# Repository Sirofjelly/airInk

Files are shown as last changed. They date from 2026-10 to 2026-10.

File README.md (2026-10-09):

# airInk

A compact ESPHome air-quality monitor built with a Sensirion SEN66, a Seeed Studio XIAO ESP32-C3, and a 1.54-inch black-and-white e-paper display.

The 200×200 black-on-white screen is made to be read from a desk at 30–40 cm. Chueli the cow shows how the air feels, with a status line in Swiss German, and all measurements are exposed to Home Assistant.

## Features

- Big CO₂, temperature, and humidity readings in Atkinson Hyperlegible Next
- Chueli the cow, with one face per air-quality status
- PM2.5 and VOC in the footer; NOx appears there when it is the reason for the status
- PM1.0, PM4.0, PM10, and NOx sent to Home Assistant
- Offline display operation after boot
- Home Assistant native API
- USB logging and ESPHome OTA updates
- Periodic full refresh to limit e-paper ghosting

## Hardware

- Sensirion SEN66
- Seeed Studio XIAO ESP32-C3
- Waveshare-compatible 1.54-inch, 200×200 black-and-white e-paper module

The display configuration currently targets ESPHome's `1.54inv2` model.

## Wiring

| XIAO pin | GPIO | SEN66 | E-paper |
|---|---:|---|---|
| D4 | 6 | SDA | — |
| D5 | 7 | SCL | — |
| D8 | 8 | — | CLK/SCL |
| D10 | 10 | — | DIN/SDA |
| D2 | 4 | — | RST/RES |
| D1 | 3 | — | DC |
| D0 | 2 | — | CS |
| D7 | 20 | — | BUSY |
| 3V3 | — | VDD | VCC |
| GND | — | GND | GND |

On the display, `SCL` and `SDA` are SPI clock and data labels; they are not an I²C bus.

Use 3.3 V power and logic. Add 4.7–10 kΩ pull-ups from SEN66 SDA and SCL to 3.3 V if they are not already present on your cable or breakout. GPIO2 and GPIO8 are ESP32-C3 strapping pins, so attached hardware must not force them to an invalid level during boot.

## Build and install

Install ESPHome in a Python virtual environment:

```bash
python3 -m venv .venv
source .venv/bin/activate
pip install esphome
```

Create your local secrets file:

```bash
cp secrets.example.yaml secrets.yaml
```

Edit `secrets.yaml`, then validate and install:

```bash
esphome config sen66-air-monitor.yaml
esphome run sen66-air-monitor.yaml
```

For the first USB installation, put the XIAO into its bootloader if necessary by holding **BOOT** while connecting USB.

## Statuses

Only one status is shown at a time; the first matching row wins. The thresholds live at the top of [`airink.h`](airink.h).

| Status | When | Chueli |
|---|---|---|
| Chueli wacht uf… | sensor still warming up | snoozing |
| Brännt's öppe? | PM2.5 above 50 µg/m³ | wide-eyed, smoke clouds |
| Fänschter uf! | CO₂ above 1400 ppm | dizzy, bell ringing |
| Raclette-Ziit? | VOC above 200 and PM2.5 above 15 on a November–March evening | licking her lips |
| Hesch gfurzt? | VOC rises by 100 or more within 5 minutes | squinting, stink lines |
| Zürcherstrass! | NOx index above 20 | coughing |
| Bitzeli stickig. | CO₂ 1000–1400 ppm | yawning |
| Z'heiss. | above 25 °C | sweating |
| Pulli aalegge. | below 19 °C | scarf, shivering |
| Hallebad-Luft. | humidity above 65 % | water drops |
| Wie i de Sahara. | humidity below 35 % | tongue out, sun |
| Alles guet. / Tiptop. / Muuh-tastisch. | everything fine (rotates every ten minutes) | happy |

## Chueli images

The faces in `images/chueli/` are generated as 1-bit PNGs from the drawings in [`tools/make_chueli.py`](tools/make_chueli.py). After changing a drawing, regenerate them with:

```bash
brew install librsvg
python tools/make_chueli.py
```

The script needs Pillow, which is already installed in the ESPHome virtual environment.

## Configuration

- Change `rotation: 90` to `rotation: 270` if the display is upside down in your enclosure.
- Change `timezone: Europe/Zurich` to your local timezone.
- If an older display is used, try `model: 1.54in` instead of `1.54inv2`.
- Tune the comfort zone and the other status thresholds in [`airink.h`](airink.h).

The display refreshes once per minute and performs a full refresh every ten updates.

The e-paper RST line is held high by an internal switch instead of being given to the display as `reset_pin`. With `reset_pin`, ESPHome resets the panel before every update, which erases the previous frame that partial refreshes compare against, so old text stays visible under the new one.

## Case

A 3D-printable mini Mac case lives in [case/](case/README.md), with an OpenSCAD source and ready-to-print STL files.

## Design credit

The original dashboard was inspired by [AQAIO](https://github.com/w4ilun/aqaio). airInk uses ESPHome's native SEN6x and Waveshare e-paper components rather than the AQAIO custom component.

## License

[MIT](LICENSE)

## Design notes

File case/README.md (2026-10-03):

# airInk mini Mac case

A 3D-printable case in the style of the 1984 Macintosh, for the SEN66, the XIAO ESP32-C3 and the 1.54-inch e-paper module.

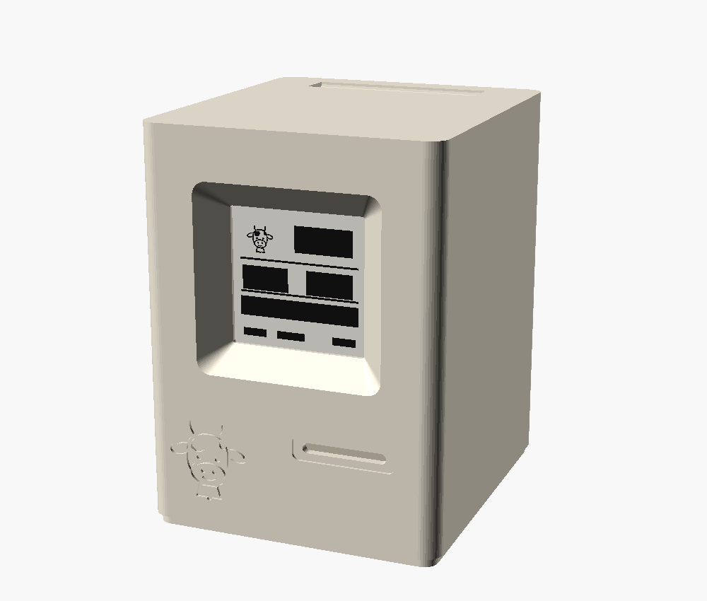
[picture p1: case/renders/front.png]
Front


| Back | Cutaway |
|---|---|
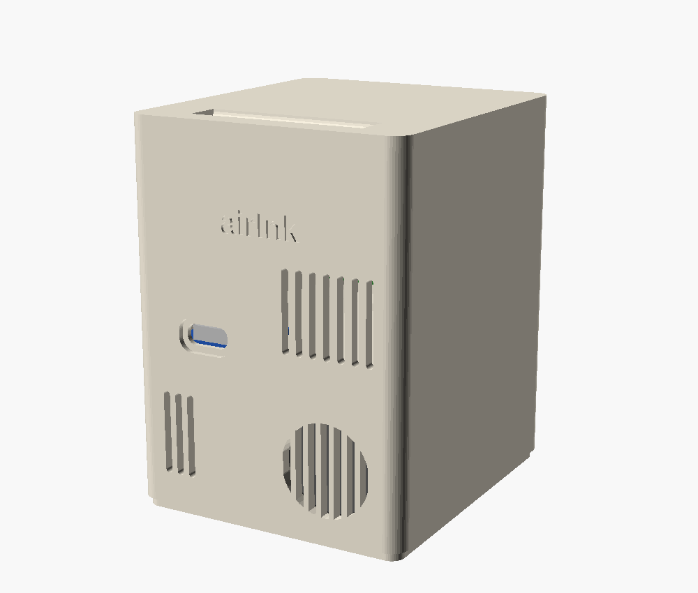
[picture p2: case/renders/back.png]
Back
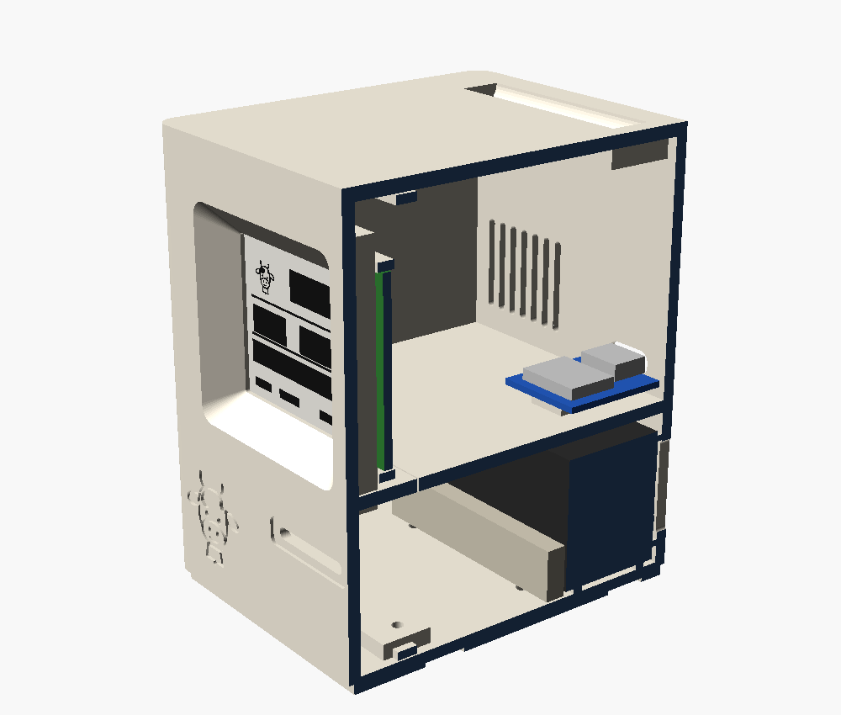
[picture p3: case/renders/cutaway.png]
Cutaway
|  |  |

Outer size: 64 × 72 × 86 mm (W × D × H).

## How it works

- **Sensor below, heat above.** The SEN66 lies in the base. A shelf separates it from the XIAO, whose heat rises out through the handle groove on top. Sensirion recommends placing the sensor below and away from heat sources.
- **Sealed airflow.** The sensor's inlet and outlet face lies against the back wall. Ribs around the inlet grille and the fan grille keep the outlet air from flowing straight back into the inlets. The grilles exceed Sensirion's minimum opening areas: about 89 mm² for the inlets (≥ 56 mm² required) and about 190 mm² for the outlet (≥ 148 mm² required).
- **The floppy slot** opens into the sensor chamber, so the case interior stays at ambient pressure.
- **The Chueli badge** sits where the original had its logo. It's the happy Chueli from the display, engraved as line art.

## Parts

| Part | Print orientation | Qty |
|---|---|---|
| `stl/shell.stl` | on its back, as exported | 1 |
| `stl/bezel.stl` | face down, as exported | 1 |
| `stl/sensor_clamp.stl` | as exported | 1 |
| `stl/display_clip.stl` | flat | 2 |

PLA or PETG, 0.2 mm layers, 3 walls, no supports. Beige or ivory filament gives the 1984 look.

## Hardware

- 4 × M2.5 × 8 mm self-tapping screws: 2 for the bezel, 2 for the sensor clamp
- 2 × M2 × 5 mm self-tapping screws for the display clips
- 4 × self-adhesive rubber feet, 8 mm diameter, up to 1 mm thick
- Double-sided foam tape for the XIAO
- A JST GH 6-pin cable for the SEN66, ideally shorter than 10 cm
- Optional: thin foam tape on the sealing ribs, and a scrap of foam to plug the cable pass-through in the shelf

## Measure before printing

The SEN66 dimensions come from the Sensirion datasheet. The other parts vary by supplier, so check them with calipers and adjust the parameters at the top of `mini-mac.scad`:

- **Display module:** `mod_w`, `mod_h` and `mod_t`. Also measure where the active area sits on your module, seen from the front: `aa_from_left` and `aa_from_top`. The defaults assume a 48 × 33 mm Waveshare module with the active area centred.
- **XIAO:** `xiao_lift` is 2.5 mm for wires soldered straight to the pads. Use about 9 mm if your XIAO has downward pin headers.

## Assembly

1. Solder the wires to the XIAO and the display. Plug the cable into the SEN66.
2. Slide the SEN66 in from the front, with its inlet/fan face against the back wall and the inlets on the right as seen from the front. Screw the clamp in from below. The slotted holes take up the sensor's tolerance.
3. Route the sensor cable up through the notch in the shelf.
4. Stick the XIAO onto its rib with the USB-C port pushed into the back-wall opening. Stick the XIAO's external antenna to the inside of the left wall.
5. Place the display in the bezel's corner guides and fix it with the two clips.
6. Slide the bezel onto the shell and screw it on from below. Add the rubber feet.

Once the display is mounted, you may need to change `rotation:` in `sen66-air-monitor.yaml` so the image is upright.

## Editing

Open `mini-mac.scad` in [OpenSCAD](https://openscad.org) to change parameters in the Customizer. Set `part` to `exploded` or `section` to look inside. To re-export a part:

```bash
openscad -D 'part="shell"' -o stl/shell.stl mini-mac.scad
```

## References

- [Sensirion SEN6x datasheet](https://sensirion.com/resource/datasheet/SEN6x): package outline and connector
- [SEN6x Mechanical Design and Assembly Guidelines](https://sensirion.com/media/documents/EA641247/682EF0DB/Sensirion_PS_AN_SEN6x_Mechanical_Design_and_Assembly_Guidelines.pdf): airflow sealing, orientation and heat sources

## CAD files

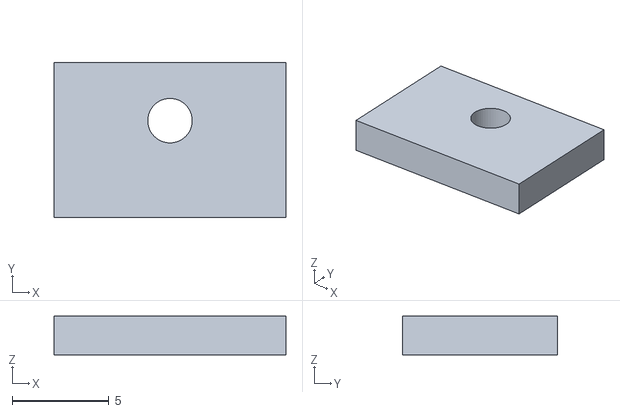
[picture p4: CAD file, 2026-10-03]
case/stl/display_clip.stl
12.0 x 8.00 x 2.00

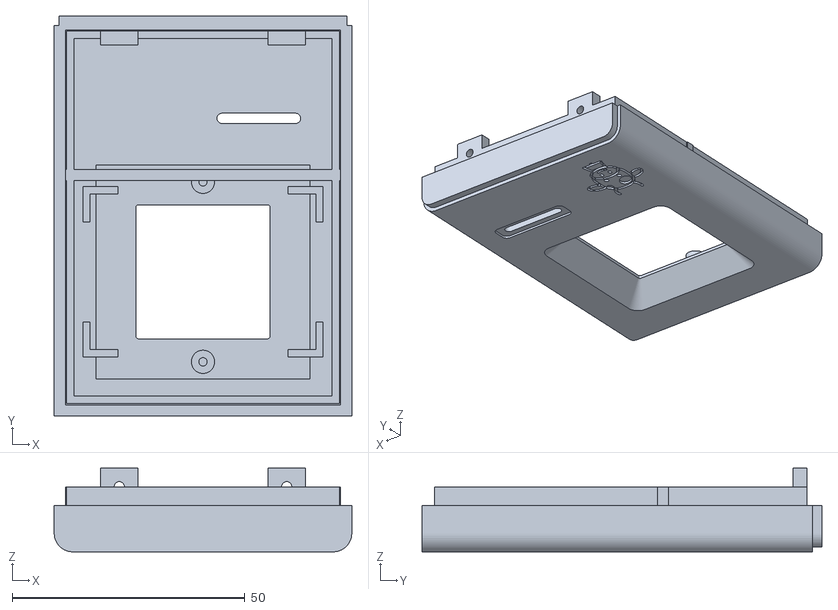
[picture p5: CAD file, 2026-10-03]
case/stl/bezel.stl
64.0 x 86.0 x 18.0

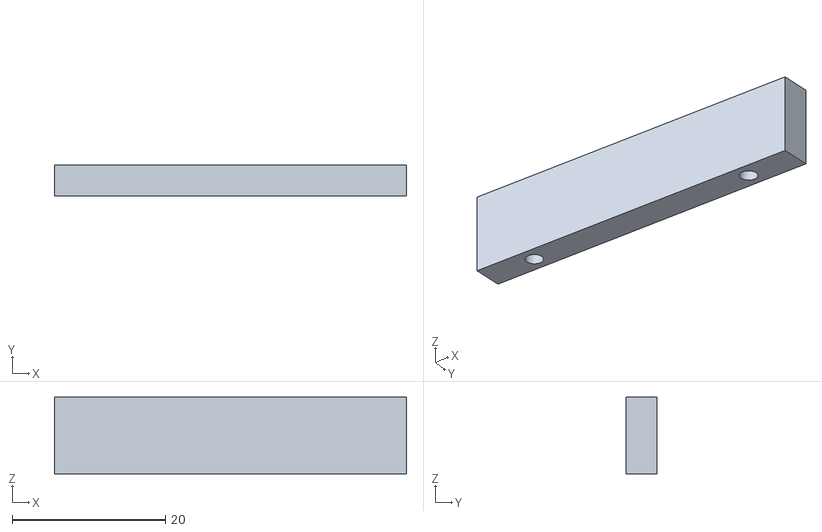
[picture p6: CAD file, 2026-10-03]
case/stl/sensor_clamp.stl
46.0 x 4.00 x 10.0

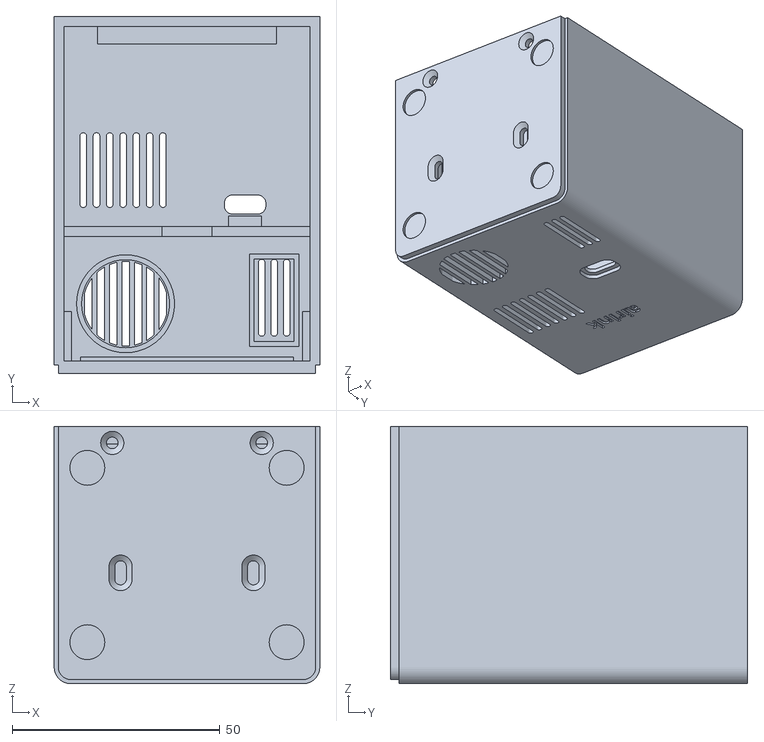
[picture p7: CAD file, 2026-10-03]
case/stl/shell.stl
64.0 x 86.0 x 62.0

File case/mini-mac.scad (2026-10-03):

// airInk mini Mac: a 3D-printable case for the SEN66, XIAO ESP32-C3 and
// 1.54" e-paper display, styled after the 1984 Macintosh.
//
// Units are millimetres. Axes: x = right (seen from the front),
// y = front face (0) to back, z = up.
//
// Printable parts (exported in print orientation):
//   openscad -D 'part="shell"'        -o shell.stl        mini-mac.scad
//   openscad -D 'part="bezel"'        -o bezel.stl        mini-mac.scad
//   openscad -D 'part="sensor_clamp"' -o sensor_clamp.stl mini-mac.scad
//   openscad -D 'part="display_clip"' -o display_clip.stl mini-mac.scad  (print 2)
//
// The SEN66 sits in the base with its inlet/outlet face against the back
// wall. The XIAO sits above a heat shelf, so its warmth rises away from the
// sensor (Sensirion SEN6x mechanical design guidelines, section 2.4).

/* [View] */
part = "assembly"; // [assembly, exploded, section, shell, bezel, sensor_clamp, display_clip]
section_x = 0;     // cut plane for the section view

/* [Case] */
W = 64;            // outer width
H = 86;            // outer height
D = 72;            // outer depth, bezel and shell together
bezel_d = 10;      // bezel depth: the front/back seam, like the original
wall = 2.4;
floor_t = 3;
r_edge = 4;        // vertical edge radius
foot_h = 2;        // recessed foot band at the bottom
foot_in = 1;
tol = 0.25;        // clearance between mating parts
lip_d = 4;         // bezel lip that slides into the shell
lip_t = 1.6;

/* [Display: Waveshare 1.54" module] */
mod_w = 48;        // module outline, mounted landscape
mod_h = 33;
mod_t = 3.2;       // panel + PCB
aa = 27.6;         // active area (square)
aa_from_left = 10.2; // module left edge to active area, seen from the front: measure yours
aa_from_top = 2.7;   // module top edge to active area: measure yours
win_z = 55;        // window centre height
win_margin = 0.6;  // window overlap beyond the active area, per side
recess = 40;       // outer size of the 45° screen recess

/* [SEN66] */
sen = [55.2, 25.6, 21.3]; // length, height, depth (datasheet fig. 11)
sen_rib = 1.0;     // sealing ribs between sensor face and back wall
shelf_z = 33;      // heat shelf: sensor below, XIAO above

/* [XIAO ESP32-C3] */
xiao_w = 17.8;
xiao_l = 21;
xiao_pcb = 1.2;
xiao_x = 14;       // centre, seen from the front
xiao_lift = 2.5;   // PCB underside above the shelf; use ~9 with downward pin headers

/* [Text] */
back_text = "airInk";
inside_text = "";  // engraved inside the back wall, e.g. your names

$fn = 48;

// ---------------------------------------------------------------- derived

iw = W - 2 * wall;
win = aa + 2 * win_margin;
rd = (recess - win) / 2;          // recess depth for 45° walls
screen_t = rd + 0.8;              // face thickness around the window
mcx = mod_w / 2 - aa_from_left - aa / 2;              // module centre x
mcz = win_z + aa_from_top + aa / 2 - mod_h / 2;        // module centre z

sen_top = floor_t + 1 + sen[1];   // sensor rests on 1 mm rails
sen_face_y = D - wall - sen_rib;  // inlet/outlet face, toward the back wall
sen_rear_y = sen_face_y - sen[2]; // connector face

// Sensor face features use datasheet coordinates: u along the length from
// the inlet end, v down from the top edge. The inlet end sits on the +x side.
function sx(u) = sen[0] / 2 - u;
function sz(v) = sen_top - v;
fan = [sx(42.4), sz(12.8)];
fan_d = 20.5;

xiao_pcb_z = shelf_z + wall + xiao_lift;
usb_z = xiao_pcb_z + xiao_pcb + 1.6;
xiao_y1 = D - wall - 0.6;         // USB-C receptacle overhangs the PCB edge
xiao_y0 = xiao_y1 - xiao_l;

shelf_y0 = bezel_d + lip_d + tol;

// ---------------------------------------------------------------- helpers

module rbox(w, d, h, r) {
    hull() for (x = [-w / 2 + r, w / 2 - r], y = [r, d - r])
        translate([x, y, 0]) cylinder(r = r, h = h);
}

module rrect(w, h, r) {
    re = min(r, min(w, h) / 2 - 0.01);
    offset(re) square([w - 2 * re, h - 2 * re], center = true);
}

// Extrude 2D children (x right, y up as seen from the front) between
// the planes y0 and y0 + depth.
module front_cut(y0, depth) {
    translate([0, y0 + depth, 0]) rotate([90, 0, 0]) linear_extrude(depth) children();
}

// Outer body between y0 and y1, including the recessed foot band.
module body(y0, y1) {
    intersection() {
        union() {
            translate([0, 0, foot_h]) rbox(W, D, H - foot_h, r_edge);
            translate([0, foot_in, 0])
                rbox(W - 2 * foot_in, D - 2 * foot_in, foot_h + 0.01, r_edge - foot_in);
        }
        translate([-W, y0, -1]) cube([2 * W, y1 - y0, H + 2]);
    }
}

module cavity(y0, y1) {
    translate([-iw / 2, y0, floor_t]) cube([iw, y1 - y0, H - floor_t - wall]);
}

// Chueli, from images/chueli/happy.svg (PR #1). Ink becomes the engraving.
// Elements are layered in SVG order, so later white fills cover earlier ink.
chueli_horn_l = [[25.00, 14.00], [24.37, 13.32], [23.81, 12.61], [23.31, 11.88], [22.89, 11.11],
    [22.53, 10.32], [22.25, 9.50], [22.03, 8.65], [21.89, 7.78], [21.81, 6.88], [21.81, 5.94],
    [21.87, 4.99], [22.00, 4.00]];
chueli_horn_r = [for (p = chueli_horn_l) [72 - p[0], p[1]]];
chueli_spot_l = [[21.00, 26.00], [21.01, 23.65], [21.48, 21.59], [22.34, 19.83], [23.52, 18.37],
    [24.93, 17.22], [26.50, 16.38], [28.15, 15.84], [29.81, 15.63], [31.41, 15.73], [32.85, 16.16],
    [34.08, 16.92], [35.00, 18.00], [35.55, 19.29], [35.72, 20.62], [35.55, 21.97], [35.07, 23.30],
    [34.34, 24.57], [33.38, 25.75], [32.23, 26.81], [30.93, 27.70], [29.52, 28.41], [28.03, 28.88],
    [26.51, 29.09], [25.00, 29.00]];
chueli_spot_r = [[47.00, 16.00], [48.17, 16.12], [49.17, 16.45], [50.00, 16.97], [50.67, 17.63],
    [51.17, 18.40], [51.50, 19.25], [51.67, 20.14], [51.67, 21.04], [51.50, 21.91], [51.17, 22.71],
    [50.67, 23.42], [50.00, 24.00], [49.25, 24.13], [48.53, 24.03], [47.84, 23.73], [47.22, 23.26],
    [46.68, 22.63], [46.25, 21.88], [45.94, 21.01], [45.78, 20.07], [45.78, 19.08], [45.97, 18.05],
    [46.37, 17.02]];
chueli_smile = [[31.00, 50.00], [32.67, 50.83], [34.33, 51.33], [36.00, 51.50], [37.67, 51.33],
    [39.33, 50.83], [41.00, 50.00]];

module chueli_band(w) {
    difference() {
        offset(r = w / 2) children();
        offset(r = -w / 2) children();
    }
}

module chueli_line(pts, w) {
    for (i = [0 : len(pts) - 2]) hull() {
        translate(pts[i]) circle(d = w);
        translate(pts[i + 1]) circle(d = w);
    }
}

module chueli_ear(x, a) { translate([x, 27]) rotate(a) scale([9, 4.5]) circle(1); }
module chueli_bell() { polygon([[28, 56], [44, 56], [46.5, 66], [25.5, 66]]); }
module chueli_head() { translate([34, 28]) offset(r = 16) square([4, 8]); }
module chueli_muzzle() { translate([36, 46]) scale([15, 9.5]) circle(1); }

module chueli() {
    ink = 2.6;
    mirror([0, 1]) translate([-36, -36]) union() {
        difference() {
            union() {
                difference() {
                    union() {
                        difference() {
                            union() {
                                chueli_band(ink) chueli_ear(12, -20);
                                chueli_band(ink) chueli_ear(60, 20);
                                chueli_line(chueli_horn_l, 3.2);
                                chueli_line(chueli_horn_r, 3.2);
                            }
                            offset(r = ink / 2) chueli_bell();
                        }
                        chueli_band(ink) chueli_bell();
                        translate([36, 67.5]) circle(2);
                    }
                    offset(r = ink / 2) chueli_head();
                }
                chueli_band(ink) chueli_head();
                polygon(chueli_spot_l);
                polygon(chueli_spot_r);
            }
            offset(r = ink / 2) chueli_muzzle();
        }
        chueli_band(ink) chueli_muzzle();
        for (x = [31, 41]) translate([x, 44]) scale([1.8, 2.4]) circle(1);
        for (x = [28, 44]) translate([x, 33]) circle(2.4);
        chueli_line(chueli_smile, 2);
    }
}

// ---------------------------------------------------------------- bezel
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

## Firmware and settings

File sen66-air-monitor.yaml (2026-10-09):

esphome:
  name: sen66-air-monitor
  friendly_name: SEN66 Air Monitor
  # Chueli's status logic and thresholds.
  includes:
    - airink.h

esp32:
  board: seeed_xiao_esp32c3
  framework:
    type: esp-idf

# Use the ESP32-C3 native USB port for logs. This leaves GPIO20/D7 free
# for the display BUSY signal.
logger:
  hardware_uart: USB_SERIAL_JTAG

api:

ota:
  - platform: esphome

wifi:
  ssid: !secret wifi_ssid
  password: !secret wifi_password

  ap:
    ssid: "SEN66 Fallback"
    password: test1234

captive_portal:

time:
  - platform: sntp
    id: network_time
    timezone: Europe/Zurich

# SEN66 I2C bus
i2c:
  id: sen66_bus
  sda: GPIO6       # D4
  scl: GPIO7       # D5
  frequency: 100kHz
  scan: true

# E-paper SPI bus
spi:
  clk_pin: GPIO8   # D8 / display CLK or SCL
  mosi_pin: GPIO10 # D10 / display DIN or SDA

sensor:
  - platform: sen6x
    type: SEN66
    i2c_id: sen66_bus
    address: 0x6B
    update_interval: 30s

    temperature:
      name: "Temperature"
      id: sen66_temperature

    humidity:
      name: "Humidity"
      id: sen66_humidity

    co2:
      name: "CO2"
      id: sen66_co2

    pm_1_0:
      name: "PM1.0"
      id: sen66_pm_1

    pm_2_5:
      name: "PM2.5"
      id: sen66_pm_2_5

    pm_4_0:
      name: "PM4.0"
      id: sen66_pm_4

    pm_10_0:
      name: "PM10"
      id: sen66_pm_10

    voc_index:
      name: "VOC Index"
      id: sen66_voc
      # Keep a few minutes of history for the "Hesch gfurzt?" detector.
      on_value:
        - lambda: airink::record_voc(x);

    nox_index:
      name: "NOx Index"
      id: sen66_nox

# Keeps the e-paper RST line (D2) high so the panel never resets between
# updates. See the note on the display below.
switch:
  - platform: gpio
    id: epaper_reset
    pin: GPIO4          # D2
    restore_mode: ALWAYS_ON
    internal: true

# Atkinson Hyperlegible Next keeps digits and letters distinct at a glance.
font:
  - file: &atkinson_bold
      type: gfonts
      family: Atkinson Hyperlegible Next
      weight: 700
    id: font_co2
    size: 44
    glyphs: "0123456789-"

  - file: *atkinson_bold
    id: font_big
    size: 40
    glyphs: "0123456789-"

  # Status line plus the small decimal and unit next to the big numbers.
  - file: *atkinson_bold
    id: font_status
    size: 20
    glyphs: &text_glyphs " !'-.:0123456789?%°…ABCDEFGHIJKLMNOPQRSTUVWXYZabcdefghijklmnopqrstuvwxyzäöüÄÖÜ"

  - file: *atkinson_bold
    id: font_time
    size: 14
    glyphs: "0123456789:-"

  - file: &atkinson_regular
      type: gfonts
      family: Atkinson Hyperlegible Next
      weight: 400
    id: font_small
    size: 14
    glyphs: *text_glyphs

  # The font has no subscript ₂, so CO₂ gets a small "2" instead.
  - file: *atkinson_regular
    id: font_subscript
    size: 10
    glyphs: "2"

# Chueli the cow, one face per status. Regenerate with tools/make_chueli.py.
image:
  - { platform: file, file: images/chueli/boot.png, id: chueli_boot, type: BINARY }
  - { platform: file, file: images/chueli/happy.png, id: chueli_happy, type: BINARY }
  - { platform: file, file: images/chueli/sleepy.png, id: chueli_sleepy, type: BINARY }
  - { platform: file, file: images/chueli/dizzy.png, id: chueli_dizzy, type: BINARY }
  - { platform: file, file: images/chueli/stink.png, id: chueli_stink, type: BINARY }
  - { platform: file, file: images/chueli/smoke.png, id: chueli_smoke, type: BINARY }
  - { platform: file, file: images/chueli/raclette.png, id: chueli_raclette, type: BINARY }
  - { platform: file, file: images/chueli/cough.png, id: chueli_cough, type: BINARY }
  - { platform: file, file: images/chueli/hot.png, id: chueli_hot, type: BINARY }
  - { platform: file, file: images/chueli/cold.png, id: chueli_cold, type: BINARY }
  - { platform: file, file: images/chueli/humid.png, id: chueli_humid, type: BINARY }
  - { platform: file, file: images/chueli/dry.png, id: chueli_dry, type: BINARY }
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

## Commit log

2026-10-03 Redesign the e-paper screen around Chueli the cow
    Replace the inverted two-column dashboard with a black-on-white layout
    sized for reading at 30–40 cm: big CO₂, temperature, and humidity in
    Atkinson Hyperlegible Next, a Swiss German status line, and a small
    footer with PM2.5, VOC (or NOx when it triggers the status), and time.
    Chueli the cow shows one of twelve moods chosen by airink.h, which
    holds all status thresholds and a short VOC history for detecting
    sudden jumps. The mood images are 1-bit PNGs generated by
    tools/make_chueli.py.
    [sen66-air-monitor.yaml]
2026-10-03 Fix e-paper ghosting by not resetting the panel between updates
    With reset_pin set, the 1.54" V2 driver puts the panel into deep sleep
    and hardware-resets it before every update. The reset erases the
    previous frame that partial refreshes diff against, so old text stayed
    visible under the new one. Hold RST high with an internal GPIO switch
    instead, so partial refreshes update cleanly.
    [sen66-air-monitor.yaml]
2026-10-03 Add 3D-printable mini Mac case
    A parametric OpenSCAD case styled after the 1984 Macintosh, with STL
    exports and renders. The SEN66 sits below a heat shelf with its inlet
    and outlet face sealed against the back-wall grilles; the XIAO sits
    above, venting through the handle groove. The front carries a Chueli
    badge and the back an airInk engraving.
    [bezel.stl, display_clip.stl, mini-mac.scad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]
